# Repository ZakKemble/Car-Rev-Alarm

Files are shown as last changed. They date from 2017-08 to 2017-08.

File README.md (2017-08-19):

Car Rev Alarm and Gear Indicator
================================

A DIY Car rev alarm and gear indicator.

http://blog.zakkemble.co.uk/car-rev-alarm-and-gear-indicator/

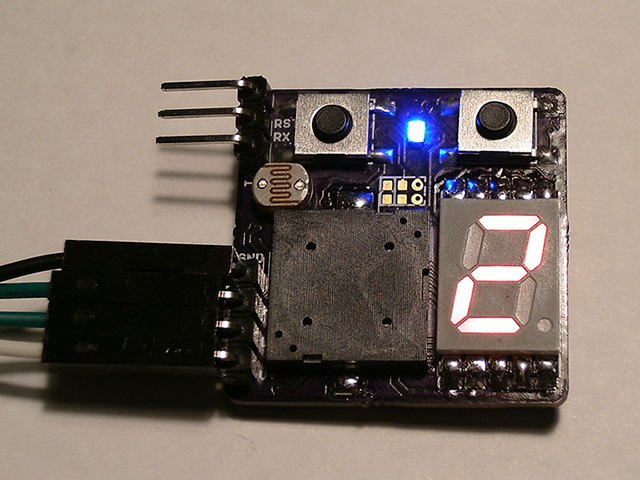
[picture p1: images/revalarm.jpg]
Rev alarm pic


---

Zak Kemble

contact@zakkemble.co.uk

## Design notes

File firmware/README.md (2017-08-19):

revAlarm
--------
This is the main code for the project.

The sketch should be compiled for 'Arduino Pro or Pro Mini' and processor 'ATmega328 (3.3V, 8MHz)'.

hex compiled for this projects hardware.

obdSim
------
This is a simple OBD simulator that responds to a few PID requests and spams random CAN frames out.

hex compiled for Arduino Uno.

optiboot
--------
This is the Arduino optiboot bootloader, slightly customised for this project.

Baud set to 250000

LED set to B7

hex compiled for this projects hardware.

Fuse Settings
-------------
Low: 0x62 (Internal RC oscillator; 6CK/14CK + 65ms startup time; Div clock by 8)

High: 0xDE (Enable SPI programming; Enable bootloader; Bootloader size 512 bytes (256 words))

Extended: 0xFD (Brownout at 2.7V)

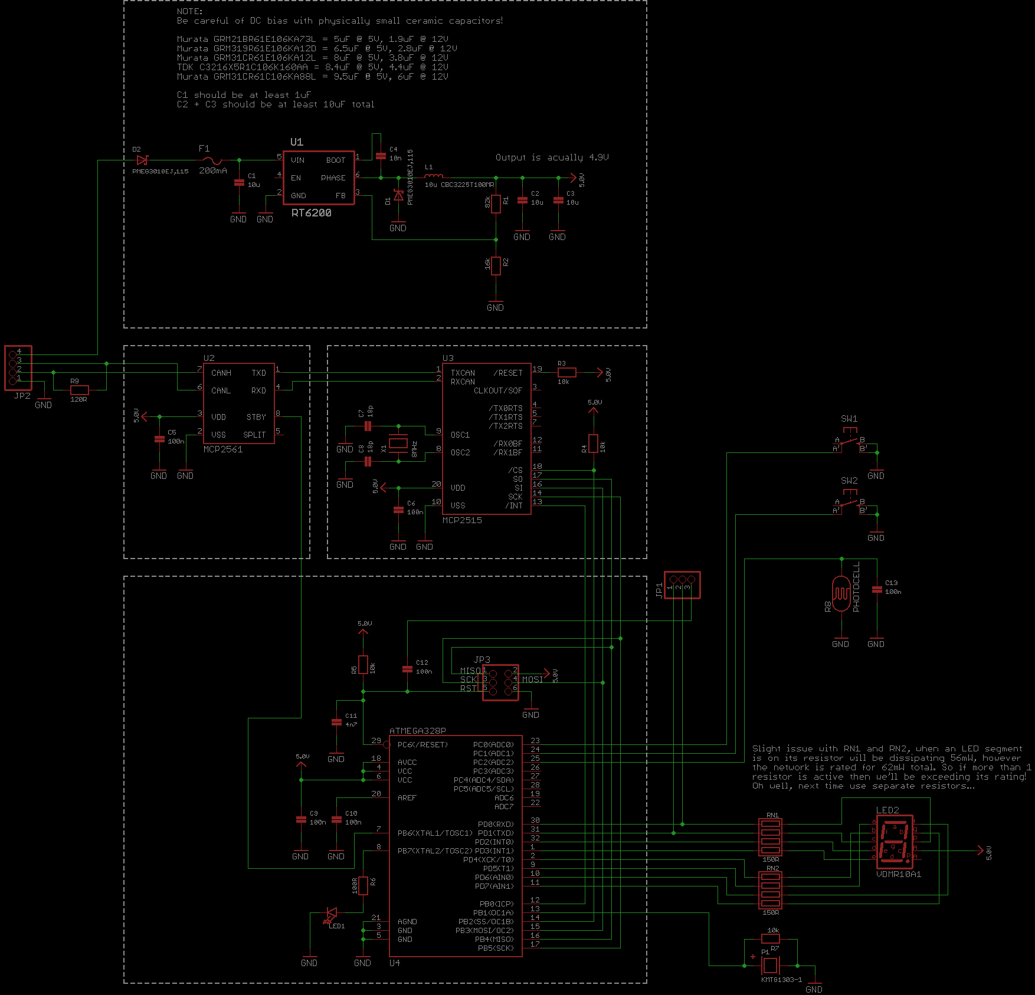
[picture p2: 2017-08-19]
hardware/schematic.png

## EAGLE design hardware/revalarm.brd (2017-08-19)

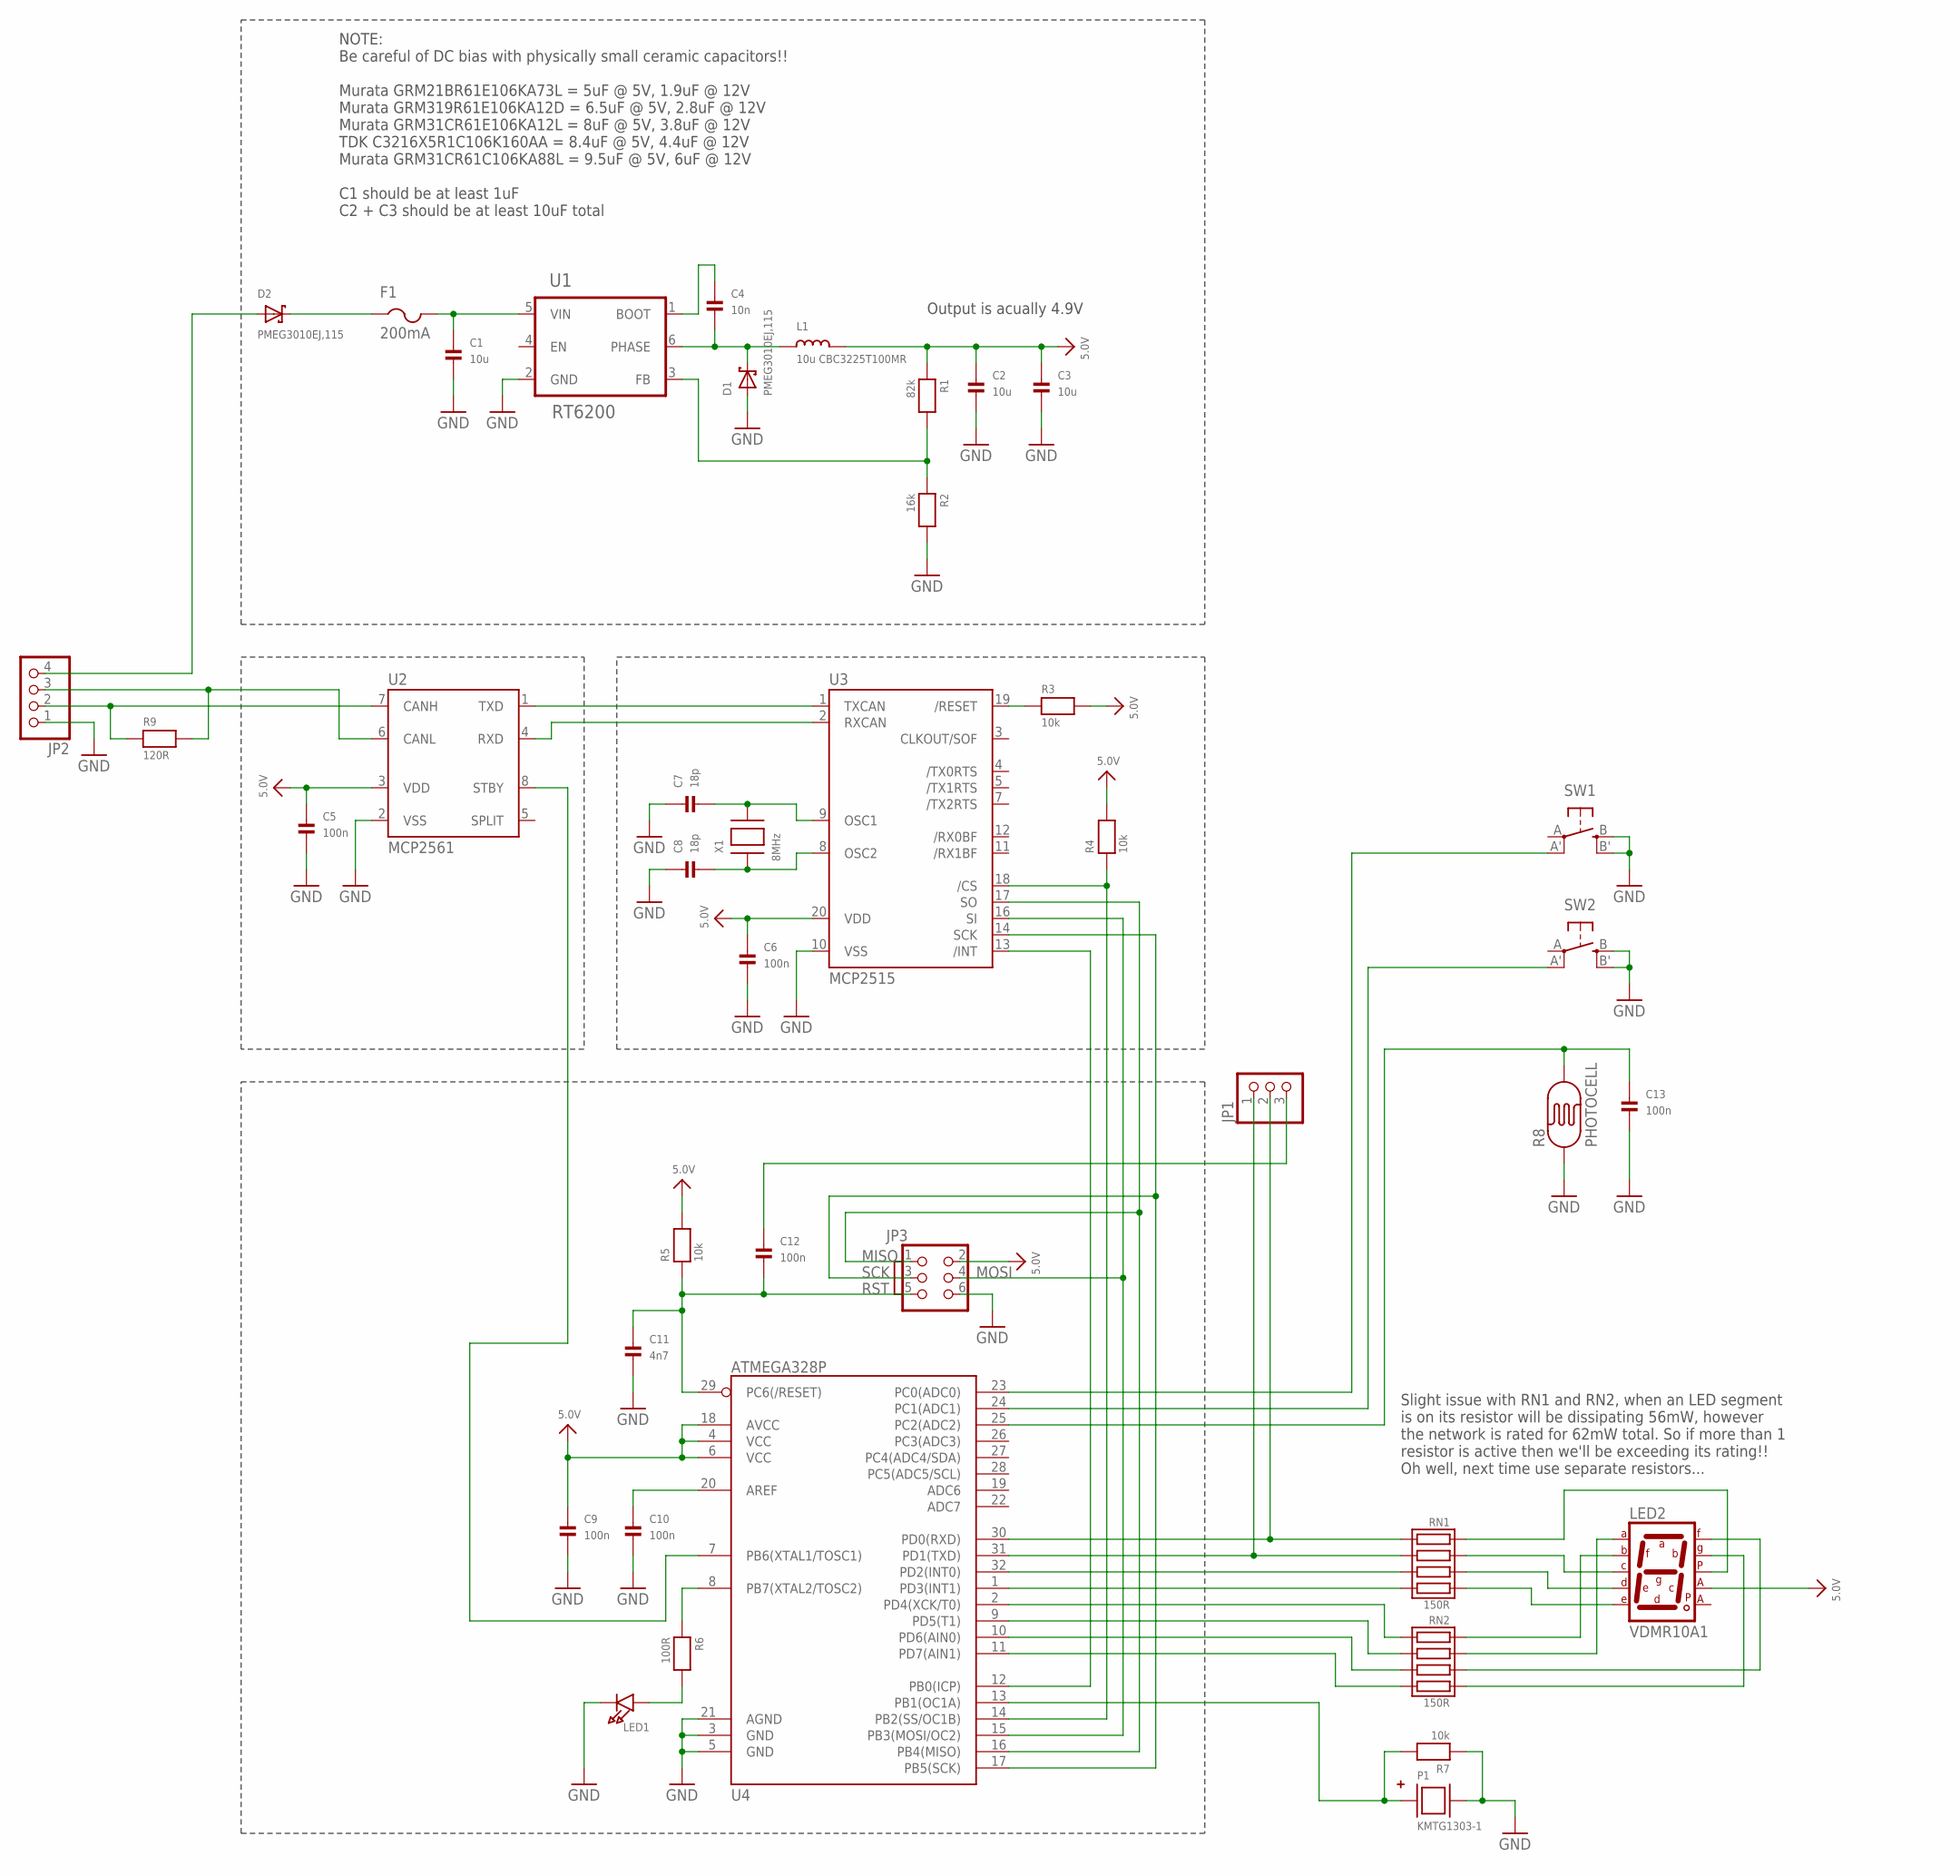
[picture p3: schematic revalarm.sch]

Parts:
C1, C2, C3: 10u; 1206
C4: 10n; 0402
C5, C6, C9, C10, C12, C13: 100n; 0402
C7, C8: 18p; 0402
C11: 4n7; 0402
D1, D2: PMEG3010EJ,115; SOD-323
F1: 200mA; 1206
JP1: PINHD-1X3; 1X03
JP2: PINHD-1X4; 1X04
JP3: ISP6PINPOGO_PIXELRGB; POGO60PIN_PIXELRGB
L1: 10u CBC3225T100MR; 1210K
LED1: LED0805_NOOUTLINE; CHIPLED_0805_NOOUTLINE
LED2: VDMR10A1; 7SEG-SMD
P1: KMTG1303-1; KMTG1303
R1: 82k; 0402
R2: 16k; 0402
R3, R4, R5, R7: 10k; 0402
R6: 100R; 0402
R8: PHOTOCELL
R9: 120R; 1206
RN1, RN2: 150R; RESPACK_4X0603
SW1, SW2: SPST_TACTMC32882; TACT_SMD4
U1: RT6200; SOT23-6_SM_PAD
U2: MCP2561; SOIC8_150MIL_SMPAD
U3: MCP2515; TSSOP20
U4: ATMEGA328P; TQFP32-08
X1: 8MHz; NX5032

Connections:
5.0V: C2.1, C3.1, C5.1, C6.1, C9.1, JP3.2, L1.2, LED2.COMM1 (CA1), R1.1, R3.2, R4.2, R5.2, U2.3 (VDD), U3.20 (VDD), U4.4 (VCC), U4.6 (VCC), U4.18 (AVCC)
GND: C1.2, C2.2, C3.2, C5.2, C6.2, C7.1, C8.1, C9.2, C10.2, C11.2, C13.2, D1.A, JP2.1, JP3.6, LED1.C, P1.P$2 (GND), R2.2, R7.1, R8.1, SW1.B (S), SW1.B' (S1), SW2.B (S), SW2.B' (S1), U1.2 (GND), U2.2 (VSS), U3.10 (VSS), U4.3 (GND), U4.5 (GND), U4.21 (AGND)
MISO: JP3.1, U3.17 (SO), U4.16 (PB4(MISO))
MOSI: JP3.4, U3.16 (SI), U4.15 (PB3(MOSI/OC2))
unnamed: C8.2, U3.8 (OSC2), X1.P$1
unnamed: C13.1, R8.2, U4.25 (PC2(ADC2))
unnamed: U2.4 (RXD), U3.2 (RXCAN)
unnamed: U2.1 (TXD), U3.1 (TXCAN)
unnamed: R4.1, U3.18 (/CS), U4.14 (PB2(SS/OC1B))
unnamed: C12.1, JP1.3
unnamed: RN2.6, U4.10 (PD6(AIN0))
unnamed: D2.C, F1.1
unnamed: C7.2, U3.9 (OSC1), X1.P$2
unnamed: LED2.G, RN2.4 (7)
unnamed: JP1.2, RN1.8 (2), U4.30 (PD0(RXD))
unnamed: C10.1, U4.20 (AREF)
unnamed: R3.1, U3.19 (/RESET)
unnamed: LED1.A, R6.2
unnamed: JP1.1, RN1.7 (4), U4.31 (PD1(TXD))
unnamed: RN1.6, U4.32 (PD2(INT0))
unnamed: RN1.5 (8), U4.1 (PD3(INT1))
unnamed: RN2.8 (2), U4.2 (PD4(XCK/T0))
unnamed: RN2.7 (4), U4.9 (PD5(T1))
unnamed: LED2.F, RN2.3 (5)
unnamed: RN2.5 (8), U4.11 (PD7(AIN1))
unnamed: LED2.A, RN2.2 (3)
unnamed: C1.1, F1.2, U1.5 (VIN)
unnamed: R1.2, R2.1, U1.3 (FB)
unnamed: C4.1, U1.1 (BOOT)
unnamed: C4.2, D1.C, L1.1, U1.6 (PHASE)
unnamed: D2.A, JP2.4
unnamed: JP2.2, R9.1, U2.7 (CANH)
unnamed: JP2.3, R9.2, U2.6 (CANL)
unnamed: U2.8 (STBY), U4.7 (PB6(XTAL1/TOSC1))
unnamed: P1.P$1 (VCC), R7.2, U4.13 (PB1(OC1A))
unnamed: LED2.B, RN2.1
unnamed: LED2.D, RN1.3 (5)
unnamed: LED2.E, RN1.4 (7)
unnamed: LED2.C, RN1.2 (3)
unnamed: LED2.DP, RN1.1
unnamed: U3.13 (/INT), U4.12 (PB0(ICP))
unnamed: SW1.A' (P1), U4.23 (PC0(ADC0))
unnamed: SW2.A' (P1), U4.24 (PC1(ADC1))
unnamed: R6.1, U4.8 (PB7(XTAL2/TOSC2))
RST: C11.1, C12.2, JP3.5, R5.1, U4.29 (PC6(/RESET))
SCK: JP3.3, U3.14 (SCK), U4.17 (PB5(SCK))

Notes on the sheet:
NOTE: Be careful of DC bias with physically small ceramic capacitors!! Murata GRM21BR61E106KA73L = 5uF @ 5V, 1.9uF @ 12V Murata GRM319R61E106KA12D = 6.5uF @ 5V, 2.8uF @ 12V Murata GRM31CR61E106KA12L = 8uF @ 5V, 3.8uF @ 12V TDK C3216X5R1C106K160AA = 8.4uF @ 5V, 4.4uF @ 12V Murata GRM31CR61C106KA88L 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
Output is acually 4.9V
Slight issue with RN1 and RN2, when an LED segment is on its resistor will be dissipating 56mW, however the network is rated for 62mW total. So if more than 1 resistor is active then we'll be exceeding its rating!! Oh well, next time use separate resistors...

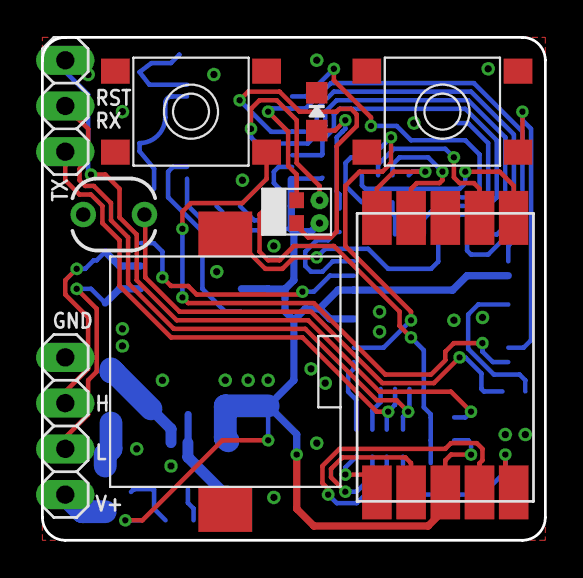
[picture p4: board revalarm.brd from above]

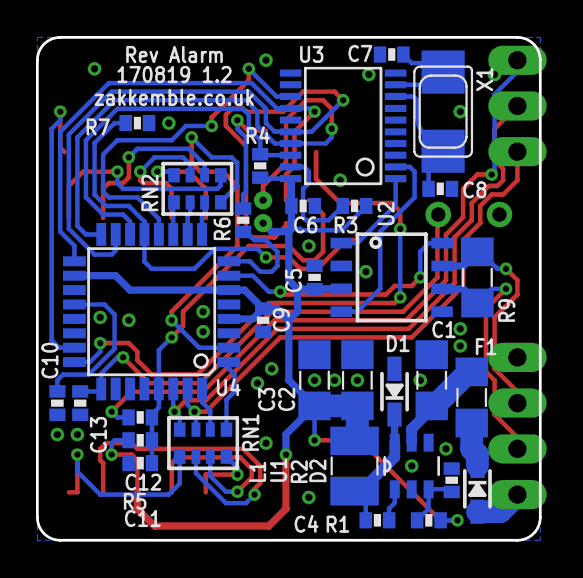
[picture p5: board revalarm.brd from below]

Board: 2 copper layers, 27.9 x 27.9 mm, 41 parts (32 on the bottom side), 46 nets.

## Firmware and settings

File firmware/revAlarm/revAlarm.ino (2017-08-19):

/*
 * Project: Car Rev Alarm and Gear Indicator
 * Author: Zak Kemble, contact@zakkemble.co.uk
 * Copyright: (C) 2017 by Zak Kemble
 * License: GNU GPL v3 (see License.txt)
 * Web: http://blog.zakkemble.co.uk/car-rev-alarm-and-gear-indicator/
 */

#include <mcp_can.h>
#include <SPI.h>
#include <EEPROM.h>
#include <avr/power.h>
#include <avr/sleep.h>
#include <avr/interrupt.h>

#define SERIAL_ENABLE	0

// These gear ratios are for a manual Honda Civic Type-S GT 2006 Hatchback
static float gearRatios[] = {
	3.142,
	1.869,
	1.303,
	1.054,
	0.853,
	0.727 // If your vehicle has 5 gears then remove this line, if it has more than 6 then just add them to the array
};
#define RATIO_FINAL 4.294 // Final drive ratio
#define WHEEL_CIRCUMFERENCE 192 //200 // Wheel circumference in centimeters, also used for fine tuning


#define CAN0_SPEED		CAN_500KBPS
#define CAN0_FOSC		MCP_8MHZ

#define PIN_CAN0_INT	8
#define PIN_BUZZER		9
#define PIN_CAN0_SS		10
#define PIN_SWITCH1		A0
#define PIN_SWITCH2		A1
#define PIN_LDR			A2
// NOTE:
// LED and MCP2561 standby are controlled via the crystal pins B6 and B7

// These are bit positions for PORTD
// They also happen to match up with the Arduino Uno pin numbers that map to PORTD
#define PIN_7SEG_A	5
#define PIN_7SEG_B	4
#define PIN_7SEG_C	1
#define PIN_7SEG_D	2
#define PIN_7SEG_E	3
#define PIN_7SEG_F	6
#define PIN_7SEG_G	7
#define PIN_7SEG_DP	0


#define PID_ID_EXTENDED	1
#define PID_ID			0x18DB33F1 // 0x7DF // Address to send requests to
#define PID_ID_RECV		0x18DAF110 // Address to receive replies from

#define DATA_PAD 0x55

#define PID_MODE_CURR_DATA	0x01

#define PID_ENGINE_RPM		0x0C
#define PID_VEHICLE_SPEED	0x0D
#define PID_NONE			0xFF


#define NUM_GEARS		(sizeof(gearRatios) / sizeof(float))
#define NUM_BTNS		2
#define CAN_TIMEOUT		200
#define CAN_REQINTERVAL	200
#define SLEEP_TIMEOUT	3000

#define EEPROM_ADDR_REV		1 // Size: 2 bytes
#define EEPROM_ADDR_7SEG	3 // Size: 1 byte

#define CAN_INTASSERTED()	(digitalRead(PIN_CAN0_INT) == LOW)

// LED and CANTRX standby control are connected to the crystal pins, which Arduino digitalRead/digitalWrite/pinMode doesn't support by default
// So we have to do some manual port manipulation
#define LED_ON()			PORTB |= _BV(PORTB7)
#define LED_OFF()			PORTB &= ~_BV(PORTB7)

#define CANTRX_DISABLE()	PORTB |= _BV(PORTB6)
#define CANTRX_ENABLE()		PORTB &= ~_BV(PORTB6)

#define XTAL_PIN_CFG()		DDRB |= _BV(DDB7)|_BV(DDB6)

#define PORT7SEGOFF			0xFF

typedef unsigned int tune_t;

static byte segChars[] = {
	_BV(PIN_7SEG_A)|_BV(PIN_7SEG_B)|_BV(PIN_7SEG_C)|_BV(PIN_7SEG_D)|_BV(PIN_7SEG_E)|_BV(PIN_7SEG_F), // 0
	_BV(PIN_7SEG_B)|_BV(PIN_7SEG_C), // 1
	_BV(PIN_7SEG_A)|_BV(PIN_7SEG_B)|_BV(PIN_7SEG_D)|_BV(PIN_7SEG_E)|_BV(PIN_7SEG_G), // 2
	_BV(PIN_7SEG_A)|_BV(PIN_7SEG_B)|_BV(PIN_7SEG_C)|_BV(PIN_7SEG_D)|_BV(PIN_7SEG_G), // 3
	_BV(PIN_7SEG_B)|_BV(PIN_7SEG_C)|_BV(PIN_7SEG_F)|_BV(PIN_7SEG_G), // 4
	_BV(PIN_7SEG_A)|_BV(PIN_7SEG_C)|_BV(PIN_7SEG_D)|_BV(PIN_7SEG_F)|_BV(PIN_7SEG_G), // 5
	_BV(PIN_7SEG_A)|_BV(PIN_7SEG_C)|_BV(PIN_7SEG_D)|_BV(PIN_7SEG_E)|_BV(PIN_7SEG_F)|_BV(PIN_7SEG_G), // 6
	_BV(PIN_7SEG_A)|_BV(PIN_7SEG_B)|_BV(PIN_7SEG_C), // 7
	_BV(PIN_7SEG_A)|_BV(PIN_7SEG_B)|_BV(PIN_7SEG_C)|_BV(PIN_7SEG_D)|_BV(PIN_7SEG_E)|_BV(PIN_7SEG_F)|_BV(PIN_7SEG_G), // 8
	_BV(PIN_7SEG_A)|_BV(PIN_7SEG_B)|_BV(PIN_7SEG_C)|_BV(PIN_7SEG_D)|_BV(PIN_7SEG_F)|_BV(PIN_7SEG_G), // 9
};

typedef enum
{
	TONE_STOP = 0,
	TONE_PAUSE = 1,
	TONE_REPEAT = 2,
	TONE_2KHZ = 250,
	TONE_2_5KHZ = 200,
	TONE_3KHZ = 166,
	TONE_3_5KHZ = 143,
	TONE_4KHZ = 125,
	TONE_4_5KHZ = 111,
	TONE_5KHZ = 100,
} tone_t;

static const tune_t tuneRevAlarm[] PROGMEM = {
	TONE_4KHZ<<8 | 200,
	TONE_PAUSE<<8 |50,
	TONE_4KHZ<<8 | 80,
	TONE_PAUSE<<8 | 50,
	TONE_4KHZ<<8 | 80,
	TONE_STOP
};

static const tune_t tuneBtnSuccess[] PROGMEM = {
	TONE_4KHZ<<8 | 80,
	TONE_PAUSE<<8 | 50,
	TONE_4_5KHZ<<8 | 80,
	TONE_STOP
};

/*
static const tune_t tuneBtnFail[] PROGMEM = {
	TONE_4KHZ<<8 | 80,
	TONE_PAUSE<<8 | 50,
	(tune_t)(TONE_2KHZ<<8 | 200), // Cast because the compiler was moaning about 'narrowing conversion of '-1336' from 'int' to 'const tune_t {aka const unsigned int}' inside { }'
	TONE_STOP
};
*/
static MCP_CAN CAN0(PIN_CAN0_SS);

static unsigned int lastActivity;
static volatile byte portValue7Seg;
static volatile byte pinValueLed;
static bool displayEnabled;

static unsigned int rpm;
static byte speed;
static byte gear;
static bool revAlarmTriggered;

static byte mode7Seg;
static unsigned int revAlarmValue;

static byte tuneIdx; // Position in tune
static const tune_t* tune; // The tune

static byte buzzLen;
static byte buzzStartTime;

static void pinSetup(void)
{
	pinMode(PIN_CAN0_INT, INPUT_PULLUP);
	pinMode(PIN_SWITCH1, INPUT_PULLUP);
	pinMode(PIN_SWITCH2, INPUT_PULLUP);
	pinMode(PIN_LDR, INPUT_PULLUP);
	pinMode(PIN_BUZZER, OUTPUT);

	XTAL_PIN_CFG();

	CANTRX_ENABLE();

	portValue7Seg = PORT7SEGOFF;
	PORTD = PORT7SEGOFF;

	pinMode(PIN_7SEG_A, OUTPUT);
	pinMode(PIN_7SEG_B, OUTPUT);
	pinMode(PIN_7SEG_C, OUTPUT);
	pinMode(PIN_7SEG_D, OUTPUT);
	pinMode(PIN_7SEG_E, OUTPUT);
	pinMode(PIN_7SEG_F, OUTPUT);
	pinMode(PIN_7SEG_G, OUTPUT);
	pinMode(PIN_7SEG_DP, OUTPUT);

	// Unused pins
	pinMode(A3, INPUT_PULLUP);
	pinMode(A4, INPUT_PULLUP);
	pinMode(A5, INPUT_PULLUP);
}

static void timerSetup(void)
{
	// Timer1 buzzer
	TCCR1A = _BV(WGM11);
	TCCR1B = _BV(CS10)|_BV(WGM13);
	OCR1A = 512;
	ICR1 = 512 * 2;

	// Timer2 brightness
	TCCR2A = 0;
	TCCR2B = _BV(CS21)|_BV(CS20);
	TIMSK2 = _BV(OCIE2A)|_BV(TOIE2);
	OCR2A = 127;
}

void setup()
{
	clock_prescale_set(clock_div_1);

	pinSetup();
	timerSetup();

	// Pin change interrupt for CAN controller and buttons
	PCMSK0 |= _BV(PCINT0);
	PCMSK1 |= _BV(PCINT8)|_BV(PCINT9);
	PCICR |= _BV(PCIE0)|_BV(PCIE1);
	//attachInterrupt(digitalPinToInterrupt(PIN_CAN0_INT), ISR_CAN, FALLING);

	// Turn ADC off (ADEN) and set prescaler to 32 instead of 128
	ADCSRA = _BV(ADPS2)|_BV(ADPS0);

	power_twi_disable();
	power_timer1_disable();
	power_timer2_disable();
	power_adc_disable();
	ACSR |= _BV(ACD);

	LED_OFF();
	delay(50);
	LED_ON();
	delay(50);
	LED_OFF();

	set_sleep_mode(SLEEP_MODE_PWR_DOWN);

#if SERIAL_ENABLE
	Serial.begin(115200);
#endif

#if SERIAL_ENABLE
	if(CAN0.begin(MCP_STDEXT, CAN0_SPEED, CAN0_FOSC) == CAN_OK)
		Serial.println(F("MCP2515 Initialized Successfully!"));
	else
		Serial.println(F("Error Initializing MCP2515..."));
#else
	CAN0.begin(MCP_STDEXT, CAN0_SPEED, CAN0_FOSC);
#endif

	// We only want to process frames with ID PID_ID_RECV
	// Masks are set to 0x1FFFFFFF so that all bits in the ID are examined to get an exact match
	CAN0.init_Mask(0, 1, 0x1FFFFFFF);
	CAN0.init_Mask(1, 1, 0x1FFFFFFF);
	for(byte i=0;i<6;i++)
		CAN0.init_Filt(i, 1, PID_ID_RECV);

	CAN0.setMode(MCP_NORMAL);
	CAN0.setSleepWakeup(1);

	// Load saved values
	EEPROM.get(EEPROM_ADDR_REV, revAlarmValue);
	EEPROM.get(EEPROM_ADDR_7SEG, mode7Seg);
	
	//revAlarmValue = 6000;

#if SERIAL_ENABLE
	Serial.print(F("Rev: "));
	Serial.println(revAlarmValue);
	Serial.print(F("7 Seg mode: "));
	Serial.println(mode7Seg);
#endif
}

void loop()
{
	CANStuff();
	display_update();
	buttons();
	buzzer_update();
	ldr();
	sleep();
}

static void display_update()
{
	if(mode7Seg == 0) // Off
		portValue7Seg = PORT7SEGOFF;
	else if(mode7Seg == 1) // Gear
	{
		if(gear > 0 && gear <= NUM_GEARS)
			portValue7Seg = ~segChars[gear];
		else
			portValue7Seg = (byte)~_BV(PIN_7SEG_G); // - (dash)
	}
	else if(mode7Seg == 2) // RPM
	{
		byte val = (rpm + 500) / 1000; // Round to nearest 1000
		if(val < 10)
			portValue7Seg = ~segChars[val];
		else
			portValue7Seg = (byte)~_BV(PIN_7SEG_G); // - (dash)
	}

	pinValueLed = revAlarmTriggered;
}

static void display_enable()
{
	if(!displayEnabled)
	{
		power_timer2_enable();
		displayEnabled = true;
	}
}

static void display_disable()
{
	if(displayEnabled)
	{
		power_timer2_disable();
		PORTD = PORT7SEGOFF;
		LED_OFF();
		displayEnabled = false;
		
		//timer2on = 0;
	}
}

static void display_setBrightness(byte brightness)
{
	if(displayEnabled)
	{
		if(brightness == 255)
		{
			power_timer2_disable();
			PORTD = portValue7Seg;
			pinValueLed ? LED_ON() : LED_OFF();
		}
		else
		{
			power_timer2_enable();
			OCR2A = ~brightness;
		}
	}
}

static void btnPress1()
{
//	if(speed == 0)
//	{
		// Only set rev alarm value if the vehicle is not moving
		revAlarmValue = rpm;

		EEPROM.put(EEPROM_ADDR_REV, revAlarmValue);
		tune_play(tuneBtnSuccess);
//	}
//	else
//		tune_play(tuneBtnFail);
}

static void btnPress2()
{
	// Change display mode
	mode7Seg++;
	if(mode7Seg > 2)
		mode7Seg = 0;

	EEPROM.put(EEPROM_ADDR_7SEG, mode7Seg);
	tune_play(tuneBtnSuccess);
}

static bool buttons_busy()
{
	return !(digitalRead(PIN_SWITCH1) && digitalRead(PIN_SWITCH2));
}

static void buttons()
{
	static bool btnState[NUM_BTNS];
	static unsigned int btnTime[NUM_BTNS];
	static bool btnDebounceOk[NUM_BTNS];

	bool btnStateNow[NUM_BTNS];

	// Get pin input states
	btnStateNow[0] = !digitalRead(PIN_SWITCH1);
	btnStateNow[1] = !digitalRead(PIN_SWITCH2);
	
	unsigned int now = millis();

	for(byte i=0;i<NUM_BTNS;i++)
	{
		if(btnStateNow[i]) // Button is currently pressed
		{
			lastActivity = now;
			display_enable();
			
			btnTime[i] = now;

			if(!btnState[i]) // Button has just been pressed (was released lat time it was checked)
			{
				if(btnDebounceOk[i])
				{
					btnDebounceOk[i] = false;

					switch(i)
					{
						case 0:
							btnPress1();
							break;
						case 1:
							btnPress2();
							break;
						default:
							break;
					}
				}
			}
		}
		else // Not pressed (or bouncing)
		{
			if((byte)(now - btnTime[i]) >= 50) // If last press was over 50ms ago then we're now ready for another press
				btnDebounceOk[i] = true;
		}
		btnState[i] = btnStateNow[i];
	}
}

static void tune_play(const tune_t* _tune)
{
	tune = _tune;
	tuneIdx = 0;
	
	// Begin playing
	tune_next();
}
/*
static void tune_stop()
{
	buzzer_buzz(TONE_STOP, 0);
}
*/
static void tune_next()
{
	// Read next tone
	unsigned int data = pgm_read_word(&tune[tuneIdx++]);

	byte len = data;
	if(len != TONE_REPEAT)
		buzzer_buzz((tone_t)(data>>8), len); // Play next tone
	else
	{
		// Repeat
		tuneIdx = 0;
		tune_next();
	}
}

static void buzzer_buzz(tone_t tone, byte len)
{
	if(tone == TONE_STOP)
	{
		buzzer_stop();
		return;
	}

	buzzLen = len;
	buzzStartTime = millis();

	// Silent pause tone
	if(tone == TONE_PAUSE)
	{
		TCCR1A &= ~(_BV(COM1A1)|_BV(COM1A0));
		power_timer1_disable();
		return;
	}

	unsigned int icr = tone * 8;
	unsigned int ocr = tone * 4;

	power_timer1_enable();
	//TIFR1 = 0;
	//TIMSK1 |= _BV(TOIE1);
	TCNT1 = 0;
	OCR1A = ocr;
	ICR1 = icr;
	TCCR1A |= _BV(COM1A1)|_BV(COM1A0);
}

static void buzzer_update()
{
	if(buzzLen && (byte)(millis() - buzzStartTime) >= buzzLen)
		tune_next();
}

static void buzzer_stop()
{
	TCCR1A &= ~(_BV(COM1A1)|_BV(COM1A0));
	power_timer1_disable();
	buzzLen = 0;
}

static void ldr()
{
	if(!displayEnabled)
		return;

	static byte lastRead;
	if((byte)(millis() - lastRead) < 50)
		return;
	lastRead = millis();

	power_adc_enable();
	ADCSRA |= _BV(ADEN);
	unsigned int val = analogRead(PIN_LDR);
	ADCSRA &= ~_BV(ADEN);
	power_adc_disable();
	
	// Brighter = lower value
	// 10 = Very bright
	// 800 = Very dark

	display_setBrightness(map(constrain(val, 60, 650), 60, 650, 255, 5));

#if SERIAL_ENABLE
//	Serial.print(F("LDR: "));
//	Serial.println(val);
#endif
}

static void sleep()
{
	if((unsigned int)(millis() - lastActivity) < SLEEP_TIMEOUT)
		return;
	else if(CAN_INTASSERTED() || buzzLen || buttons_busy())
		return;

/*
	// TODO debugging
	display_enable();
	pinValueLed = 0;
	delay(50);
	pinValueLed = 1;
	delay(50);
	//pinValueLed = 0;
*/

#if SERIAL_ENABLE
	Serial.println(F("SLEEP"));
#endif

	CAN0.setMode(MCP_SLEEP);

#if SERIAL_ENABLE
	Serial.flush();
#endif

	display_disable();
	speed = 0;
	rpm = 0;
	gear = 0;
	revAlarmTriggered = 0;

	cli();
	if(!CAN_INTASSERTED() && !buttons_busy())
	{
		//pinValueLed = 0;
		//LED_OFF();
		//PORTD = PORT7SEGOFF;
		pinMode(PIN_LDR, INPUT);
		CANTRX_DISABLE();

		sleep_enable();
		sleep_bod_disable();
		sei();
		sleep_cpu();
		sleep_disable();

		CANTRX_ENABLE();
		pinMode(PIN_LDR, INPUT_PULLUP);

		lastActivity = millis();
	}
	sei();

	// Timer2 will be enabled later if a valid reponse from the ECU is received
	//power_timer2_enable();

#if SERIAL_ENABLE
	Serial.println(F("WAKE"));
#endif

	CAN0.setMode(MCP_NORMAL);
}

static void revAlarm()
{
	if(rpm >= revAlarmValue)
	{
		if(!revAlarmTriggered)
		{
			revAlarmTriggered = true;
			tune_play(tuneRevAlarm);
		}
	}
	else
		revAlarmTriggered = false;
}

static void calcGear()
{
	gear = 0;
	if(speed == 0 || rpm == 0)
		return;

	// TODO 1666.66 is so we use kilometers per hour instead of cm per minute??
	// I can't remember how I got this value lol
	float currentGearRatio = rpm / (((1666.66f / WHEEL_CIRCUMFERENCE) * RATIO_FINAL) * speed);

	// TODO
	// Need to allow a larger difference at lower speeds since the speed is
	// in whole kph numbers and doesn't change much, while the RPM can change a lot
	float allowableRange;
	if(speed < 26)
		allowableRange = (((float)speed + 1) / (float)speed) + 0.01f;
	else
		allowableRange = 1.05f; // 5%

#if SERIAL_ENABLE
//	Serial.print(allowableRange);
//	Serial.print(F(","));
#endif

	while(1)
	{
		if(gear >= NUM_GEARS)
		{
			gear = 0;
			break;
		}

		float diff = gearRatios[gear] / currentGearRatio;
		
		gear++;

		if(diff < allowableRange && diff > 2 - allowableRange)
			break;
	}
}

static void CANStuff()
{
	static bool waitingForResponse;
	static unsigned int requestSentTime;
	static byte nextPIDRequest = PID_NONE;
	
	unsigned int now = millis();

	if(!CAN_INTASSERTED())
	{
		if(waitingForResponse && (unsigned int)(now - requestSentTime) >= CAN_TIMEOUT)
		{
			// Request timed out, restart PID request batch
			waitingForResponse = false;
			nextPIDRequest = PID_NONE;
			requestSentTime = now - CAN_REQINTERVAL;
#if SERIAL_ENABLE
			Serial.println(F("CAN Request timed out"));
#endif
		}
	}
	else
	{
		unsigned long rxId;
		byte len;
		byte rxBuf[CAN_MAX_CHAR_IN_MESSAGE];

#if SERIAL_ENABLE
		Serial.println(F("Checking for messages..."));
#endif

		if(CAN0.readMsgBuf(&rxId, &len, rxBuf) == CAN_OK)
		{
#if SERIAL_ENABLE
			char msgString[128];
			if(rxId & CAN_IS_EXTENDED) // Determine if ID is standard (11 bits) or extended (29 bits)
				sprintf_P(msgString, PSTR("Extended ID: 0x%.8lX  DLC: %hhu  Data:"), (rxId & CAN_EXTENDED_ID), len);
			else
				sprintf_P(msgString, PSTR("Standard ID: 0x%.3lX       DLC: %hhu  Data:"), rxId, len);

			Serial.print(msgString);

			for(byte i=0;i<len;i++)
			{
				sprintf_P(msgString, PSTR(" 0x%.2X"), rxBuf[i]);
				Serial.print(msgString);
			}
			Serial.println();
#endif

			if(
				(rxId & CAN_EXTENDED_ID) == PID_ID_RECV &&
				rxBuf[1] == (PID_MODE_CURR_DATA | 0x40)
			)
			{
				//power_timer0_disable();
				lastActivity = now;
				display_enable();

				if(rxBuf[2] == PID_ENGINE_RPM)
				{
					rpm = rxBuf[3]<<8 | rxBuf[4];
					rpm /= 4;

#if SERIAL_ENABLE
					Serial.print(F("*RPM: "));
					Serial.println(rpm);
#endif

					revAlarm();

					waitingForResponse = false;
				}
				else if(rxBuf[2] == PID_VEHICLE_SPEED)
				{
					speed = rxBuf[3];

#if SERIAL_ENABLE
					Serial.print(F("*MPH: "));
					Serial.println(speed * 0.621371f);
#endif

					calcGear(); // PID_VEHICLE_SPEED is the last of the batch, now work out gear

					waitingForResponse = false;

#if SERIAL_ENABLE
					//Serial.begin(115200);
					Serial.print(rpm);
					Serial.print(F(","));
					Serial.print(speed);
					Serial.print(F(","));
					Serial.println(gear);
#endif
				}
			}
#if SERIAL_ENABLE
			else
				Serial.println(F("Bad CAN ID or PID mode is not current"));
#endif
		}
#if SERIAL_ENABLE
		else
			Serial.println(F("Interrupt is asserted, but there are no messages"));
#endif
	}

	if(!waitingForResponse)
	{
		if(nextPIDRequest != PID_NONE || (unsigned int)(now - requestSentTime) >= CAN_REQINTERVAL)
		{
			if(nextPIDRequest == PID_NONE)
				nextPIDRequest = PID_ENGINE_RPM;

			CANRequest(nextPIDRequest);
			waitingForResponse = true;
			requestSentTime = now;

			// Decide what PID to get next
			switch(nextPIDRequest)
			{
				case PID_ENGINE_RPM:
				  nextPIDRequest = PID_VEHICLE_SPEED;
				  break;
				default:
				  nextPIDRequest = PID_NONE;
				  break;
			}
		}
	}
}

static void CANRequest(byte pid)
{
#if SERIAL_ENABLE
	static byte counter;
	counter++;
#endif

	byte data[] = {
		0x02, // Length
		PID_MODE_CURR_DATA,
		pid,
		DATA_PAD,
		DATA_PAD,
		DATA_PAD,
		DATA_PAD,
#if SERIAL_ENABLE
		counter
#else
		DATA_PAD
#endif
	};

#if SERIAL_ENABLE
	if(CAN0.sendMsgBuf(PID_ID, PID_ID_EXTENDED, sizeof(data), data) == CAN_OK)
		Serial.println(F("Message Sent Successfully!"));
	else
		Serial.println(F("Error Sending Message..."));
#else
	CAN0.sendMsgBuf(PID_ID, PID_ID_EXTENDED, sizeof(data), data);
#endif
}

ISR(TIMER2_COMPA_vect)
{
	PORTD = portValue7Seg;
	pinValueLed ? LED_ON() : LED_OFF();
}

ISR(TIMER2_OVF_vect)
{
	PORTD = PORT7SEGOFF;
	LED_OFF();
}

// CAN controller wakeup
EMPTY_INTERRUPT(PCINT0_vect);

// Button wakeup
EMPTY_INTERRUPT(PCINT1_vect);

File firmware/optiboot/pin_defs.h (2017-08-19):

/*
 * pin_defs.h
 * optiboot helper defining the default pin assignments (LED, SOFT_UART)
 * for the various chips that are supported.  This also has some ugly macros
 * for selecting among various UARTs and LED possibilities using command-line
 * defines like "UART=2 LED=B5"
 *
 * Copyright 2013-2015 by Bill Westfield.
 * Copyright 2010 by Peter Knight.
 * This software is licensed under version 2 of the Gnu Public Licence.
 * See optiboot.c for details.
 */

/*------------------------------------------------------------------------ */
#if defined(__AVR_ATmega168__) || defined(__AVR_ATmega168P__) || defined(__AVR_ATmega328P__) || defined(__AVR_ATmega88) || defined(__AVR_ATmega8__) || defined(__AVR_ATmega88__) || defined(__AVR_ATmega328__) // ZAK
/*------------------------------------------------------------------------ */

/* Onboard LED is connected to pin PB5 in Arduino NG, Diecimila, and Duemilanove
 */ 
#if !defined(LED)
#define LED B5
#endif

/* Ports for soft UART */
#ifdef SOFT_UART
#define UART_PORT   PORTD
#define UART_PIN    PIND
#define UART_DDR    DDRD
#define UART_TX_BIT 1
#define UART_RX_BIT 0
#endif
#endif

/*
 * Handle devices with up to 4 uarts (eg m1280.)  Rather inelegantly.
 * Note that mega8/m32 still needs special handling, because ubrr is handled
 * differently.
 */
#if UART == 0
# define UART_SRA UCSR0A
# define UART_SRB UCSR0B
# define UART_SRC UCSR0C
# define UART_SRL UBRR0L
# define UART_UDR UDR0
#elif UART == 1
#if !defined(UDR1)
#error UART == 1, but no UART1 on device
#endif
# define UART_SRA UCSR1A
# define UART_SRB UCSR1B
# define UART_SRC UCSR1C
# define UART_SRL UBRR1L
# define UART_UDR UDR1
#elif UART == 2
#if !defined(UDR2)
#error UART == 2, but no UART2 on device
#endif
# define UART_SRA UCSR2A
# define UART_SRB UCSR2B
# define UART_SRC UCSR2C
# define UART_SRL UBRR2L
# define UART_UDR UDR2
#elif UART == 3
#if !defined(UDR1)
#error UART == 3, but no UART3 on device
#endif
# define UART_SRA UCSR3A
# define UART_SRB UCSR3B
# define UART_SRC UCSR3C
# define UART_SRL UBRR3L
# define UART_UDR UDR3
#endif

#if defined(__AVR_ATmega8__) || defined (__AVR_ATmega32__) || defined (__AVR_ATmega16__)
  //Name conversion R.Wiersma
  #define UCSR0A	UCSRA
  #define UDR0 		UDR
  #define UDRE0 	UDRE
  #define RXC0		RXC
  #define FE0           FE
  #define TIFR1 	TIFR
  #define WDTCSR	WDTCR
#endif
#if defined (__AVR_ATmega32__) || defined (__AVR_ATmega16__)
  #define WDCE		WDTOE
#endif

/* Luminet support */
/*------------------------------------------------------------------------ */
#if defined(__AVR_ATtiny84__)
/*------------------------------------------------------------------------ */
/* Red LED is connected to pin PA4 */ 
#if !defined(LED)
#define LED         A4
#endif

/* Ports for soft UART - left port only for now. TX/RX on PA2/PA3 */
#ifdef SOFT_UART
#define UART_PORT   PORTA
#define UART_PIN    PINA
#define UART_DDR    DDRA
#define UART_TX_BIT 2
#define UART_RX_BIT 3
#endif
#endif

/*------------------------------------------------------------------------ */
/* Sanguino support (and other 40pin DIP cpus) */
#if defined(__AVR_ATmega644P__) || defined(__AVR_ATmega1284P__) || defined(__AVR_ATmega32__) || defined (__AVR_ATmega16__)
/*------------------------------------------------------------------------ */
/* Onboard LED is connected to pin PB0 on Sanguino */ 
#if !defined(LED)
#define LED         B0
#endif

/* Ports for soft UART */
#ifdef SOFT_UART
#define UART_PORT   PORTD
#define UART_PIN    PIND
#define UART_DDR    DDRD
#define UART_TX_BIT 1
#define UART_RX_BIT 0
#endif
#endif

/*------------------------------------------------------------------------ */
/* Mega support */
#if defined(__AVR_ATmega1280__)
/*------------------------------------------------------------------------ */
/* Onboard LED is connected to pin PB7 on Arduino Mega */ 
#if !defined(LED)
#define LED         B7
#endif

/* Ports for soft UART */
#ifdef SOFT_UART
#define UART_PORT   PORTE
#define UART_PIN    PINE
#define UART_DDR    DDRE
#define UART_TX_BIT 1
#define UART_RX_BIT 0
#endif
#endif

/*
 * ------------------------------------------------------------------------
 * A bunch of macros to enable the LED to be specifed as "B5" for bit 5 
 * of port B, and similar.
 */

#define A0 0x100
#define A1 0x101
#define A2 0x102
#define A3 0x103
#define A4 0x104
#define A5 0x105
#define A6 0x106
#define A7 0x107

#define B0 0x200
#define B1 0x201
#define B2 0x202
#define B3 0x203
#define B4 0x204
#define B5 0x205
#define B6 0x206
#define B7 0x207

#define C0 0x300
#define C1 0x301
#define C2 0x302
#define C3 0x303
#define C4 0x304
#define C5 0x305
#define C6 0x306
#define C7 0x307

#define D0 0x400
#define D1 0x401
#define D2 0x402
#define D3 0x403
#define D4 0x404
#define D5 0x405
#define D6 0x406
#define D7 0x407

#define E0 0x500
#define E1 0x501
#define E2 0x502
#define E3 0x503
#define E4 0x504
#define E5 0x505
#define E6 0x506
#define E7 0x507
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

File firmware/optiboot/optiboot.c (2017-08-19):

#define FUNC_READ 1
#define FUNC_WRITE 1
/**********************************************************/
/* Optiboot bootloader for Arduino                        */
/*                                                        */
/* http://optiboot.googlecode.com                         */
/*                                                        */
/* Arduino-maintained version : See README.TXT            */
/* http://code.google.com/p/arduino/                      */
/*  It is the intent that changes not relevant to the     */
/*  Arduino production envionment get moved from the      */
/*  optiboot project to the arduino project in "lumps."   */
/*                                                        */
/* Heavily optimised bootloader that is faster and        */
/* smaller than the Arduino standard bootloader           */
/*                                                        */
/* Enhancements:                                          */
/*   Fits in 512 bytes, saving 1.5K of code space         */
/*   Higher baud rate speeds up programming               */
/*   Written almost entirely in C                         */
/*   Customisable timeout with accurate timeconstant      */
/*   Optional virtual UART. No hardware UART required.    */
/*   Optional virtual boot partition for devices without. */
/*                                                        */
/* What you lose:                                         */
/*   Implements a skeleton STK500 protocol which is       */
/*     missing several features including EEPROM          */
/*     programming and non-page-aligned writes            */
/*   High baud rate breaks compatibility with standard    */
/*     Arduino flash settings                             */
/*                                                        */
/* Fully supported:                                       */
/*   ATmega168 based devices  (Diecimila etc)             */
/*   ATmega328P based devices (Duemilanove etc)           */
/*                                                        */
/* Beta test (believed working.)                          */
/*   ATmega8 based devices (Arduino legacy)               */
/*   ATmega328 non-picopower devices                      */
/*   ATmega644P based devices (Sanguino)                  */
/*   ATmega1284P based devices                            */
/*   ATmega1280 based devices (Arduino Mega)              */
/*                                                        */
/* Alpha test                                             */
/*   ATmega32                                             */
/*                                                        */
/* Work in progress:                                      */
/*   ATtiny84 based devices (Luminet)                     */
/*                                                        */
/* Does not support:                                      */
/*   USB based devices (eg. Teensy, Leonardo)             */
/*                                                        */
/* Assumptions:                                           */
/*   The code makes several assumptions that reduce the   */
/*   code size. They are all true after a hardware reset, */
/*   but may not be true if the bootloader is called by   */
/*   other means or on other hardware.                    */
/*     No interrupts can occur                            */
/*     UART and Timer 1 are set to their reset state      */
/*     SP points to RAMEND                                */
/*                                                        */
/* Code builds on code, libraries and optimisations from: */
/*   stk500boot.c          by Jason P. Kyle               */
/*   Arduino bootloader    http://arduino.cc              */
/*   Spiff's 1K bootloader http://spiffie.org/know/arduino_1k_bootloader/bootloader.shtml */
/*   avr-libc project      http://nongnu.org/avr-libc     */
/*   Adaboot               http://www.ladyada.net/library/arduino/bootloader.html */
/*   AVR305                Atmel Application Note         */
/*                                                        */

/* Copyright 2013-2015 by Bill Westfield.                 */
/* Copyright 2010 by Peter Knight.                        */
/*                                                        */
/* This program is free software; you can redistribute it */
/* and/or modify it under the terms of the GNU General    */
/* Public License as published by the Free Software       */
/* Foundation; either version 2 of the License, or        */
/* (at your option) any later version.                    */
/*                                                        */
/* This program is distributed in the hope that it will   */
/* be useful, but WITHOUT ANY WARRANTY; without even the  */
/* implied warranty of MERCHANTABILITY or FITNESS FOR A   */
/* PARTICULAR PURPOSE.  See the GNU General Public        */
/* License for more details.                              */
/*                                                        */
/* You should have received a copy of the GNU General     */
/* Public License along with this program; if not, write  */
/* to the Free Software Foundation, Inc.,                 */
/* 59 Temple Place, Suite 330, Boston, MA  02111-1307 USA */
/*                                                        */
/* Licence can be viewed at                               */
/* http://www.fsf.org/licenses/gpl.txt                    */
/*                                                        */
/**********************************************************/
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

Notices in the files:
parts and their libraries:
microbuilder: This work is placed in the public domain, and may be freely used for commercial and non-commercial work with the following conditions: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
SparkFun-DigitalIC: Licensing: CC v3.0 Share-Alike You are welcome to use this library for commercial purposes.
